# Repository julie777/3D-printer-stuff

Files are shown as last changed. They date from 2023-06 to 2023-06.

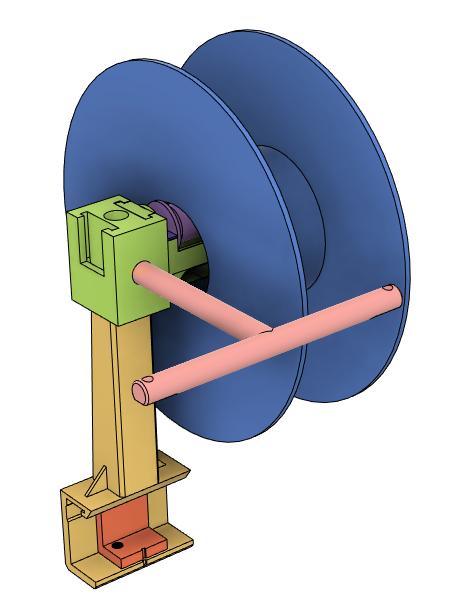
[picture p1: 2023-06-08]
Filament-Spool-Holder/filament-spool-holder.png

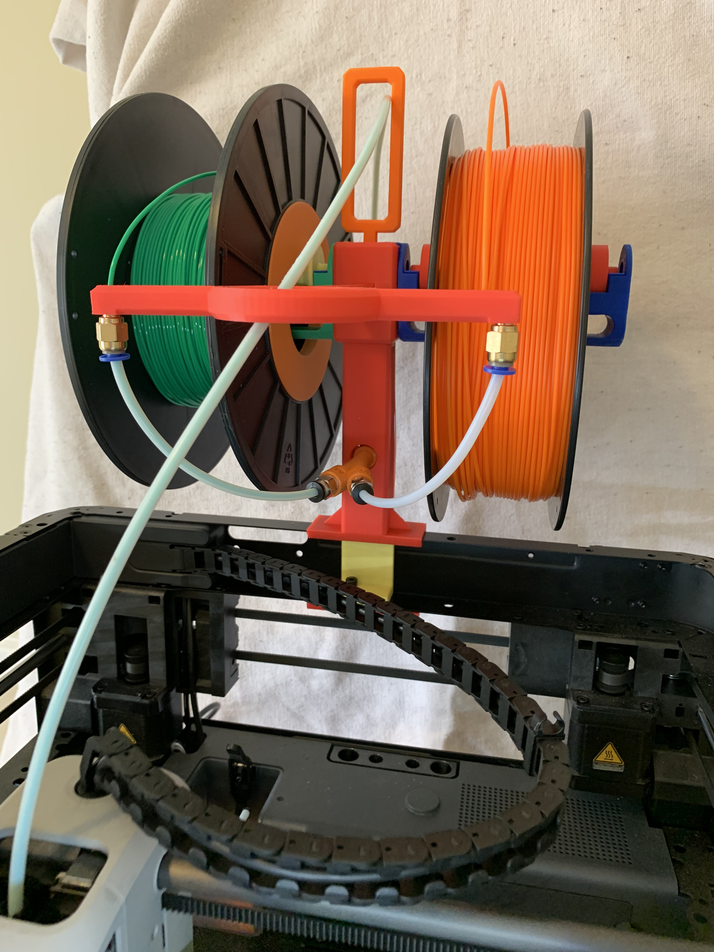
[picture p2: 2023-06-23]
Filament-Spool-Holder/filament spool holder.JPEG

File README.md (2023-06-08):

# 3D-printer-stuff

# License
This work is licensed under CC BY-NC 4.0. To view a copy of this license, visit http://creativecommons.org/licenses/by-nc/4.0/

## Spool Holder

The Spool Holder has a separate readme in its sub-directory.

### Attribution

The connection of the spindle holder to the supporting structure is the mounting system from
[Filler - The Customizable Filament Holder](https://www.thingiverse.com/thing:3020026) by HugoHuge,
which is licensed under Creative Commons - Attribution - Non-Commercial - Share Alikelicense.
The design of the spindle holder and spindle is a modified version of the corresponding parts
from the same model.

The mounting arm for the Bambu Lab P1P incorporates the clamp to hold it to the upper frame of
the printer from [Bambu Lab P1P Dual Top Spool Holder](https://www.printables.com/model/441742-bambu-lab-p1p-dual-top-spool-holder) by Mike Hall which is licensed under
Creative Commons (4.0 International License) Attribution-NonCommercial.

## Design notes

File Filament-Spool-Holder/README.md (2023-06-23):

Filament Top-Mount Spool Holder for Bambu Lab P1P

# What

I wanted a dual holder for the top of my P1P that allowed easy spool changes and visability of the
remaining filament.

I really like the dual spool holder on my Prusa, which I modified with an easy way to capture the
end of the filament for the spool not being used.

# Why

I had been using a top mount spool holder that worked very well. ??? However, given the position of my printer and the fact that most of the filament I buy comes on spools with solid sides, it was hard to check the amount of filament left.

In addition, I wanted to try a spool holder with bearings so that there was less friction than
the typical plastic on plastic that normal spool holders have.

I had one more constraint. I wanted to keep the spools of filament from protruding to the back more than the space required for the cord, with its straight out plug. (I designed my poop chute to also fit in that amount of space.)

## How

I found a very nice system that seemed to meet my needs (holder1) [Filler - The Customizable Filament Holder](https://www.thingiverse.com/thing:3020026).
It has bearings and a universal mounting system so that the part holding the spool can be
used on a free standing holder, or on some kind of printer mount. However, it did not have a mount for the P1P.

I also found a spool holder that mounted on the P1P (holder2) [Bambu Lab P1P Dual Top Spool Holder](https://www.printables.com/model/441742-bambu-lab-p1p-dual-top-spool-holder).
The only part I wanted was the part that clamped onto the P1P frame rail.

After creating a mounting arm to fit the P1P I started using the system. I did not like the excessive amount of PTFE tubing that was needed to run it in a way similar to holder 2. I also found out later than my choice of 4mm/2mm tubing commonly sold as Bowden tube is not the best when filament is being pulled and the tube is just a guide. BBL tubing has an internal diameter of 2.5mm to make it have less friction.

After using it for a while I found that sometimes the spools would climb over the small lip at the end of the spindle. I also have some spools that come with only a partial inner cylinder to ride on the spool holder. That led to creating an adapter ring for the inconvenient spools.

Then I redesigned the spindle and spindle holder to keep the spools in place better. I kept the same mounting system that holder1 had so that my spindle holder is compatible with all existing mounts.

I found that bearings are very smooth, but have so little friction that the spool tends to unwind itself. I use the solid half bearing design from holder1 modified for my spindle holder. After running through a few spools I started hearing squeaking. It turned out to be the plastic bearings. I put a very tiny amount of silicone grease on them and all is good.

I moved the filament guide bar from the top to the front as part of an experiment to shorten the filament path. That required switching the tool head cable and adding a cable chain. It works well, but I would still like to find a way to shape the PTFE tube so it has a better path.

## Printing and Assembly

The parts are arranged on plates in what I think is the best orientation for printing. The spindle holder will need supports. I am currently struggling to find supports that produce good results and require minimal cleanup.

The seam in the spindle will need to be smoothed to eliminate the bump.

The filament guide does not have the threads required to install the PTFE tubing holder with M6 threads (actually it is a pipe thread with a diameter close to M10).

The hole next to the hole for feeding filament is a holder for the filament end of the second spool. It still needs some work to find the exact dimensions and taper to allow it to work 100% of the time.

I used this splitter https://www.printables.com/model/471428-y-splitter-for-the-bambu-lab-x1c-ams.

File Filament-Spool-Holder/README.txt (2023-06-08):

Filament Top-Mount Spool Holder for Bambu Lab P1P

Why

I had been using a top mount spool holder that worked very well. ??? However, given the position of my printer and the fact that most of the filament I buy comes on spools with solid sides, it was hard to check the amount of filament left.

I really like the dual spool holder on my Prusa, which I modified with an easy way to capture the end of the filament for the spool not being used. In addition, I wanted to try a spool holder with bearings so that there was less friction than the typical plastic on plastic.

I had one more constraint. I wanted to keep the spools of filament from protruding to the back more than the space required for the cord, with its straight out plug. (I designed my poop chute to also fit in that amount of space.)

How

I found a very nice system that seemed to meet my needs (holder1) ???. It has bearings and a universal mounting system so that the part holding the spool can be used on a free standing holder, or on some kind of printer mount. However, it did not have a mount for the P1P.

I also found a spool holder that mounted on the P1P (holder2) ???. The only part I wanted was the part that clamped onto the P1P frame rail.

After creating a mounting arm to fit the P1P I started using the system. I did not like the excessive amount of PTFE tubing that was needed to run it in a way similar to holder 2. I also found out later than my choice of 4mm/2mm tubing commonly sold as Bowden tube is not the best when filament is being pulled and the tube is just a guide. BBL tubing has an internal diameter of 2.5mm to make it have less friction.

After using it for a while I found that sometimes the spools would climb over the small lip at the end of the spindle. I also have some spools that come with only a partial inner cylinder to ride on the spool holder. That led to creating an adapter ring for the inconvenient spools.

Then I redesigned the spindle and spindle holder to keep the spools in place better. I kept the same mounting system that holder1 had so that my spindle holder is compatible with all existing mounts.

I found that bearings are very smooth, but have so little friction that the spool tends to unwind itself. I use the solid half bearing design from holder1 modified for my spindle holder. After running through a few spools I started hearing squeaking. It turned out to be the plastic bearings. I put a very tiny amount of silicone grease on them and all is good.

I moved the filament guide bar from the top to the front as part of an experiment to shorten the filament path. That required switching the tool head cable and adding a cable chain. It works well, but I would still like to find a way to shape the PTFE tube so it has a better path.

Attribution

This filament spool holder could be considered a remix of ??? merged with the clamp part of ??? so that it works on the P1P.

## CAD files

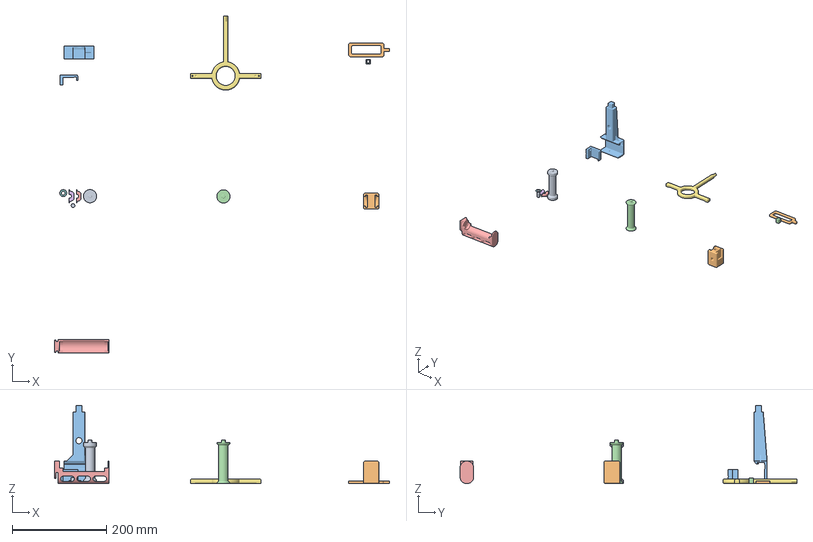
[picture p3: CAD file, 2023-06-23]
Filament-Spool-Holder/spool holder.3mf
710.5 x 713.8 x 166.0 mm
spindle body.stl
top filament guide 75.stl
Clamp.stl
post top adapter.stl
solid bearing.stl x 2
filament guide 3.stl
spindle bearing spacer.stl
spindle end pin.stl
post top.stl
P1P mounting arm.stl
spindle body wide.stl
spindle holder.stl

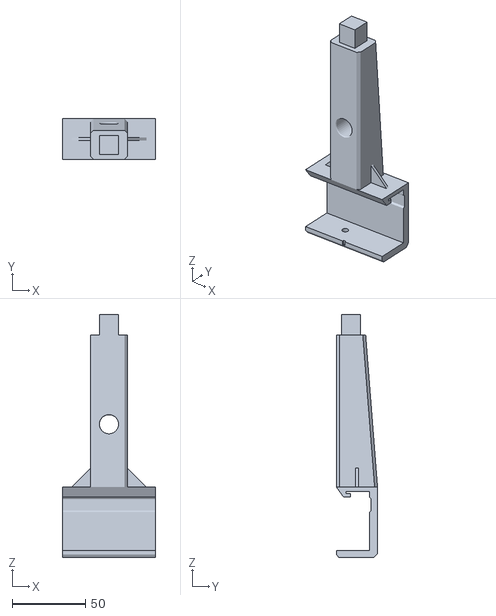
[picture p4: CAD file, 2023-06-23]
Filament-Spool-Holder/STL/P1P mounting arm.stl
63.8 x 28.1 x 166.0

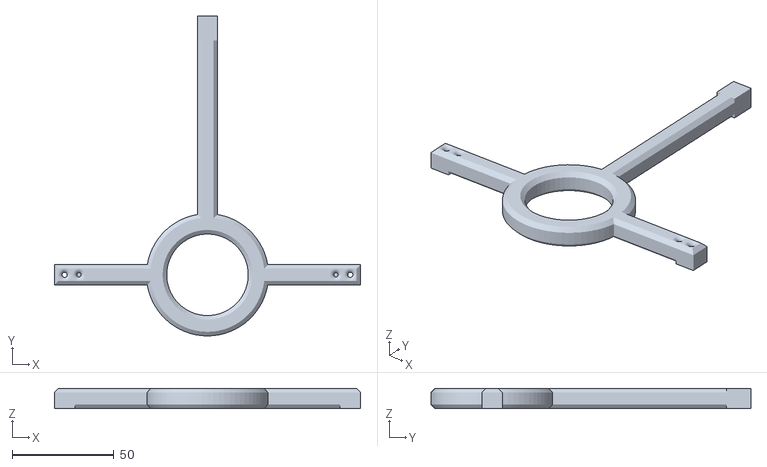
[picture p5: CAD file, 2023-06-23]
Filament-Spool-Holder/STL/filament guide.stl
150.2 x 157.0 x 10.0

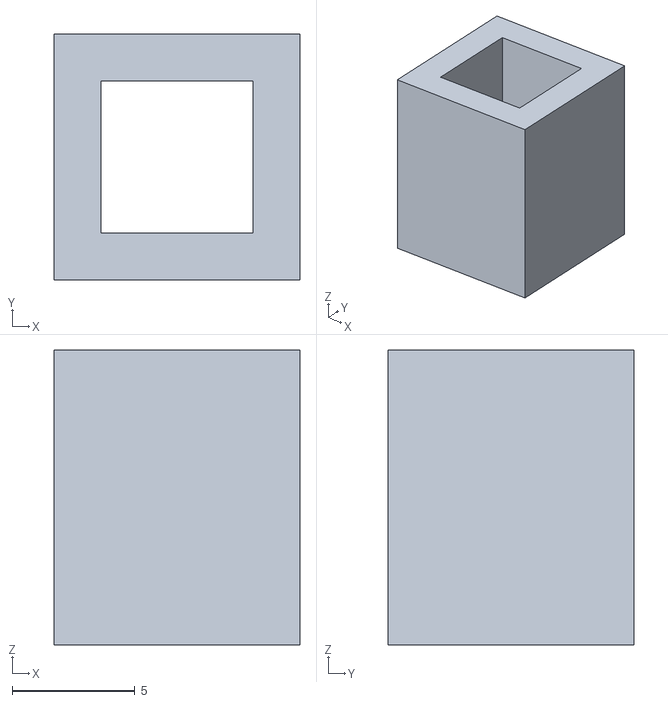
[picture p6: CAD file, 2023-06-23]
Filament-Spool-Holder/STL/post top adapter.stl
10.0 x 10.0 x 12.0

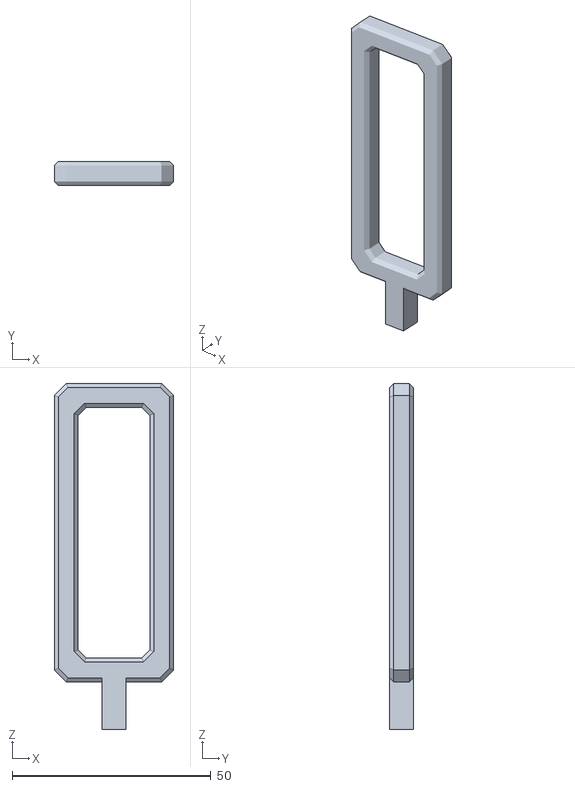
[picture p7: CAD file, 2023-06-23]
Filament-Spool-Holder/STL/top filament guide 75.stl
30.0 x 6.00 x 87.0

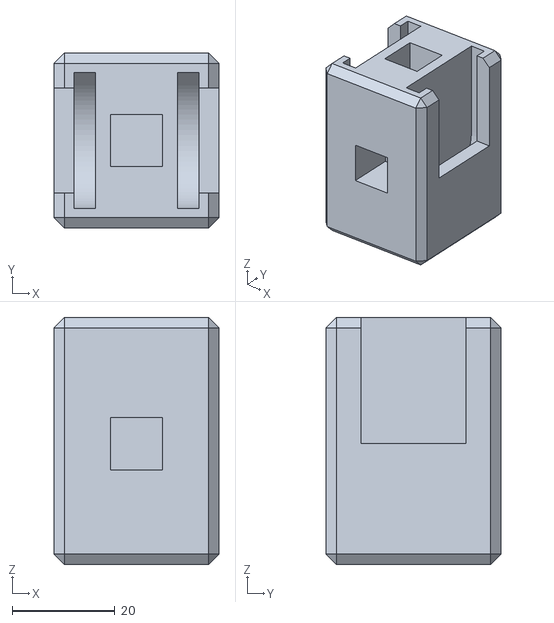
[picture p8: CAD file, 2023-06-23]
Filament-Spool-Holder/STL/post top.stl
32.0 x 34.0 x 48.0

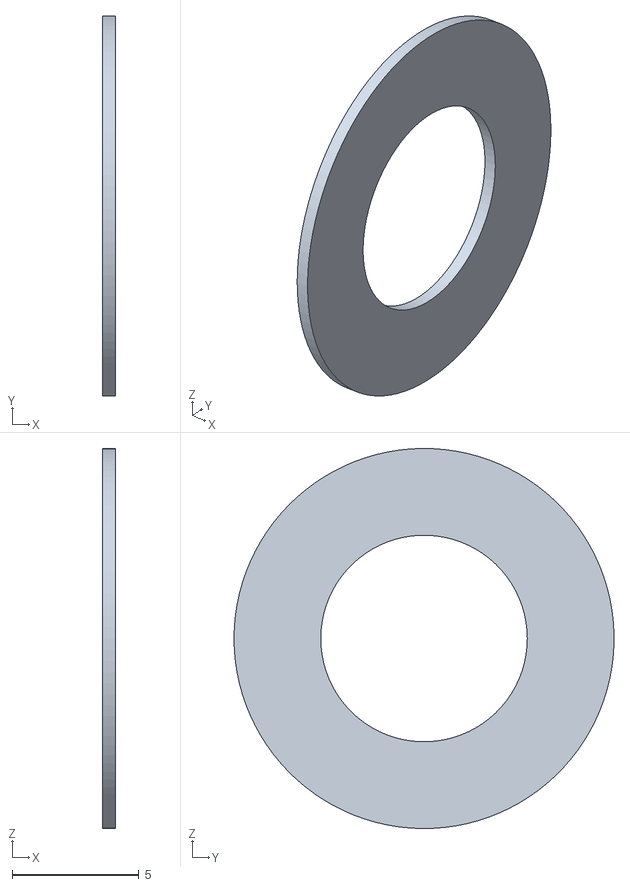
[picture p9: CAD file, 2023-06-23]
Filament-Spool-Holder/STL/spindle bearing spacer.stl
0.5 x 15.0 x 15.0

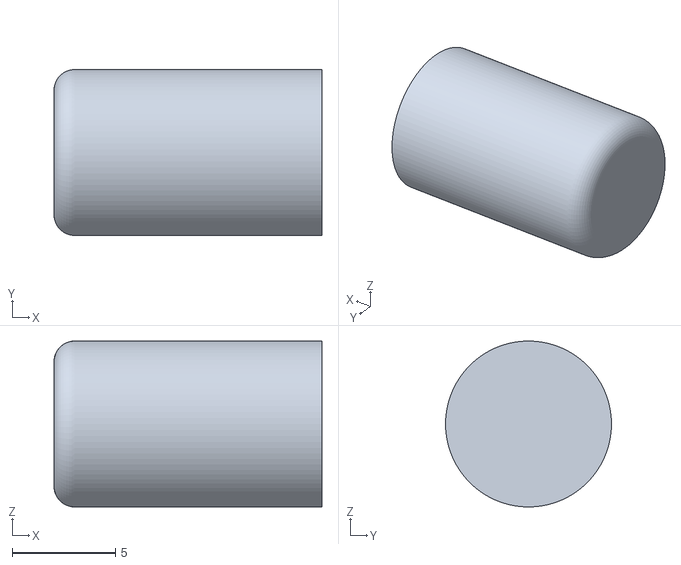
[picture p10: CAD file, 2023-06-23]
Filament-Spool-Holder/STL/spindle end pin.stl
13.0 x 8.05 x 8.04

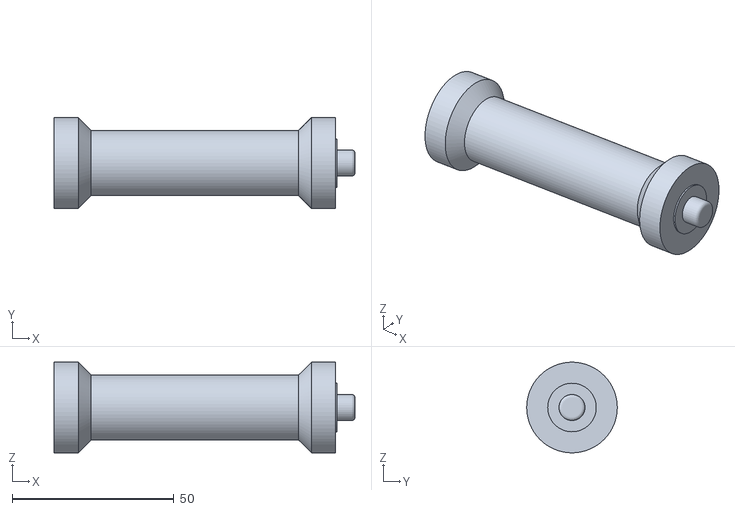
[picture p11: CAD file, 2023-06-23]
Filament-Spool-Holder/STL/spindle body narrow.stl
93.0 x 28.0 x 28.0

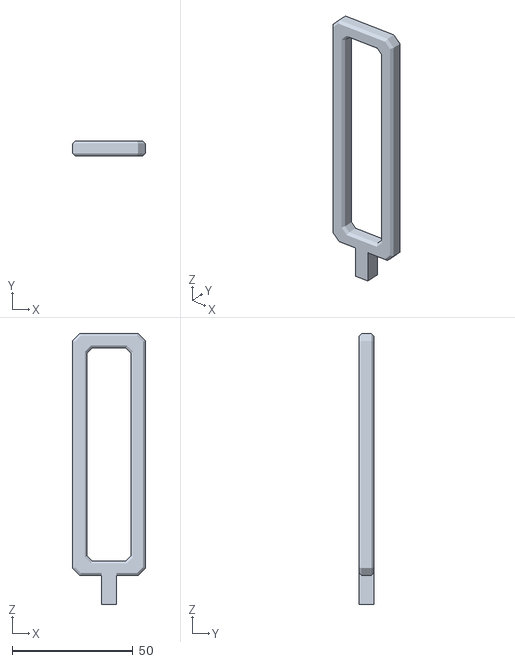
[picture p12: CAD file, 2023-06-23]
Filament-Spool-Holder/STL/top filament guide.stl
30.0 x 6.00 x 112.0

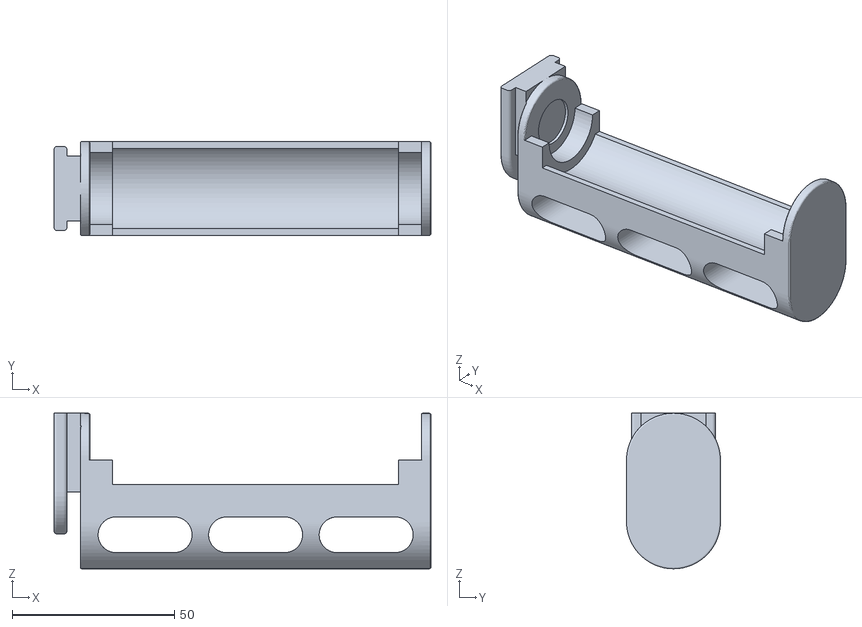
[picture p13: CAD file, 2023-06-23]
Filament-Spool-Holder/STL/spindle holder.stl
116.3 x 29.0 x 48.0

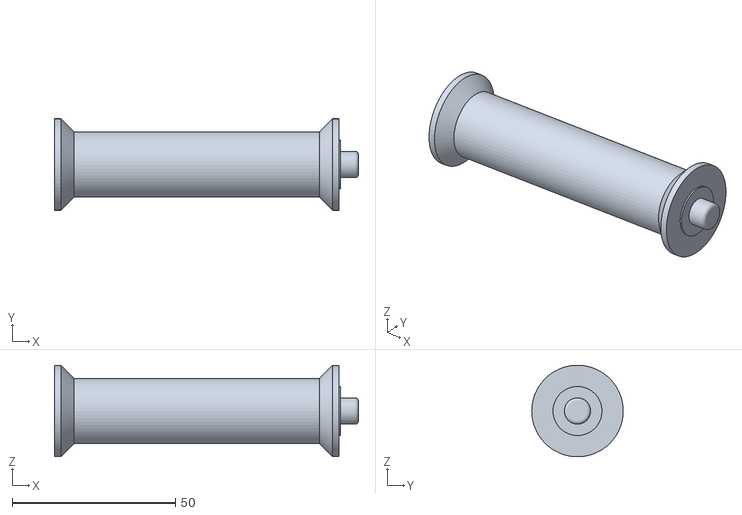
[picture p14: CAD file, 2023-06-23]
Filament-Spool-Holder/STL/spindle body wide.stl
93.0 x 28.0 x 28.0

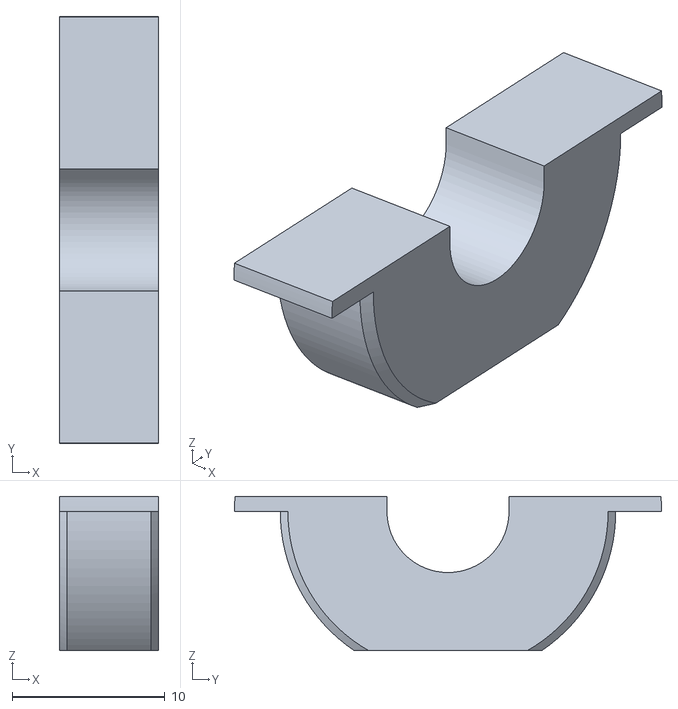
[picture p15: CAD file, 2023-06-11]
Filament-Spool-Holder/STL/solid bearing.stl
6.50 x 28.0 x 10.1

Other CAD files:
Filament-Spool-Holder/STL/spindle.stl
Filament-Spool-Holder/Filament-Spool-Holder-v12.f3d
Filament-Spool-Holder/spool holder v13.f3d
Filament-Spool-Holder/spool holder v16.f3d

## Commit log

2023-06-08 Initial check-in of filament spool holder
    [P1P mounting arm.stl, filament guide.stl, post top.stl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]
2023-06-11 Finished updating new spindle and holder design
    [Filament-Spool-Holder-v12.f3d, post top.stl, solid bearing.stl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]
2023-06-16 new filament guide design
    [filament guide 3.stl, filament guide plus.stl, post adapter.stl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]
2023-06-23 Significant redesign of spool holder to make it easier to print parts and to help parts self locate
    [P1P mounting arm.stl, filament guide 3.stl, filament guide plus.stl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]
